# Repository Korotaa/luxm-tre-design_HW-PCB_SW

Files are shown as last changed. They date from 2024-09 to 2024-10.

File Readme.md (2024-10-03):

# TSL25711 sensor with LoRa module and ESP32 chip 

## Bloc Diagramm

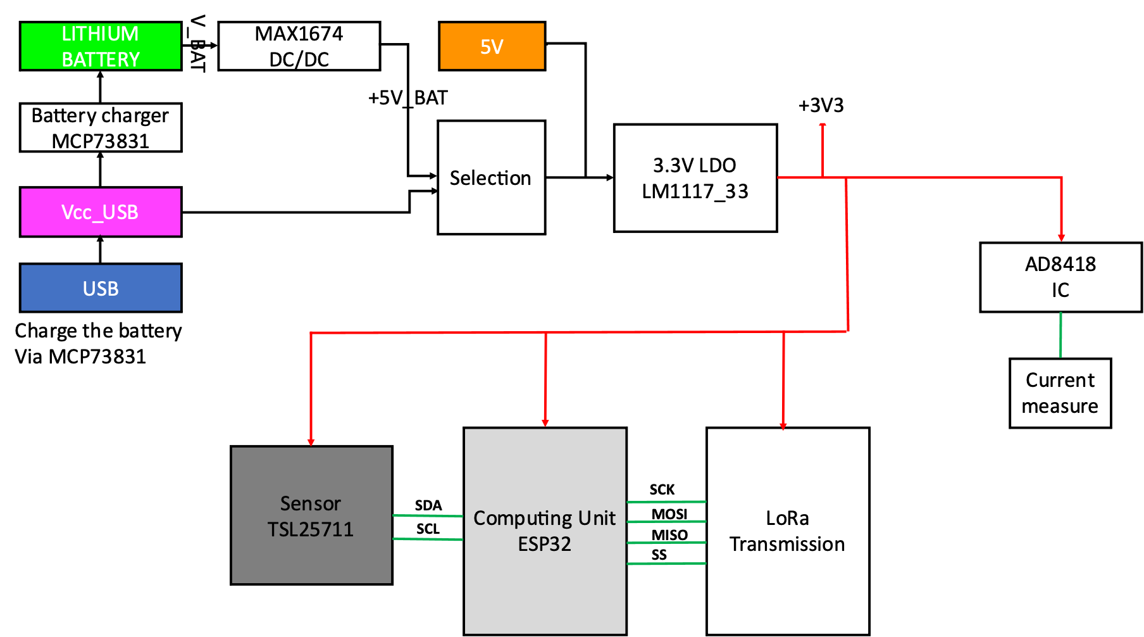
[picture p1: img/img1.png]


Le module est un End Device LoRa. C'est un dispositif IoT permettant de mesurer le niveau de luminosité grace au capteur TSL2571 et transmettre ces données à un serveur LoRaWAN (NetWork Serveur + Application Serveur) . Il peut recevoir des informations de commandes downlink de l'utilisateur.

- RF-LORA-868-SO : Transceiver LoRa pour la transmission et la reception de données sans fils. Il communique avec le MCU via une interface SPI. MISO_L pour l'envoie de données du transceiver vers le MCU et MOSI_L pour l'envoie des données du MCU vers le transceiver.
- TSL25711 : Dispositif sensible à la lumière ambiante. La valeur de sortie du capteur est transférée au MCU via l'interface I2C. Le MCU determine la valeur en LUX du rayonnement lumineux grace à une formule empirique. On retrouve le capteur dans les écrans de pc ou des smartphones. L'objectif est afin d’adapter l’intensité lumineuse émise par l’écran à la lumière ambiante, l’objectif étant de réduire la consommation de l’écran qui peut représenter jusqu’à 40% de l’énergie consommée.  
- MCU est un ESP32 
- Le dispositif possède 3 modes d'alimentations : USB, battery, ou par une alimentation externe. Lorsque le module est alimentée par USB, la batterie est chargée par la même occasion via le circuit MCP73831. 
- Il existe plusieurs points de tests permettant de visualiser grâce un oscilloscope les trames LoRa, la consommation de la carte etc...
- Le End Device est utilisé pour adapter l'éclairement d'un laboratoire en fonction de la lumière ambiante. 

- Le firmware est dévéloppé avec ESP-IDF. 

## PCB

<!-- ![](./img/routage.png) -->

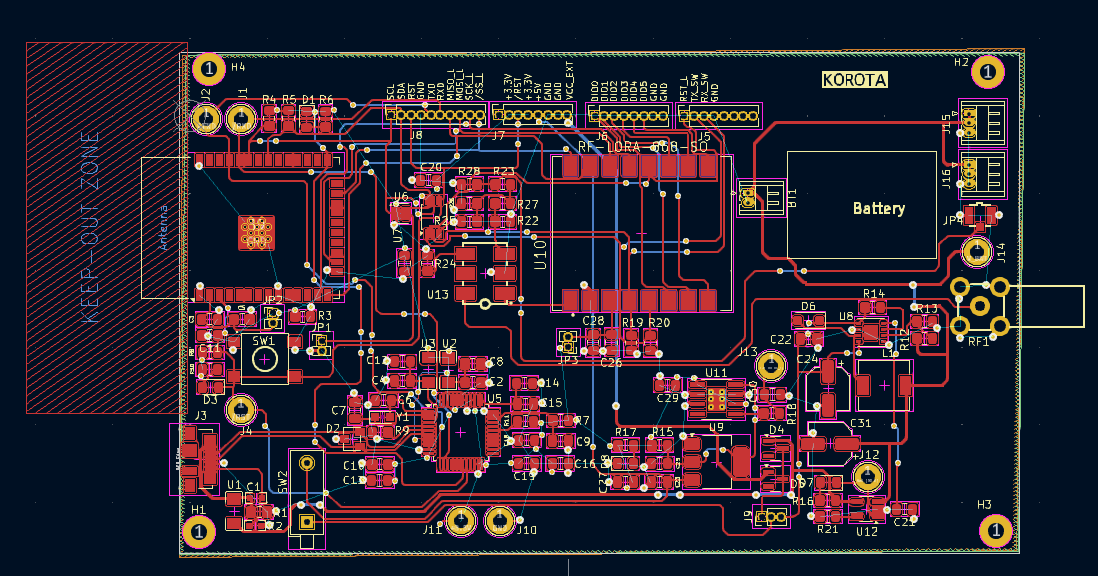
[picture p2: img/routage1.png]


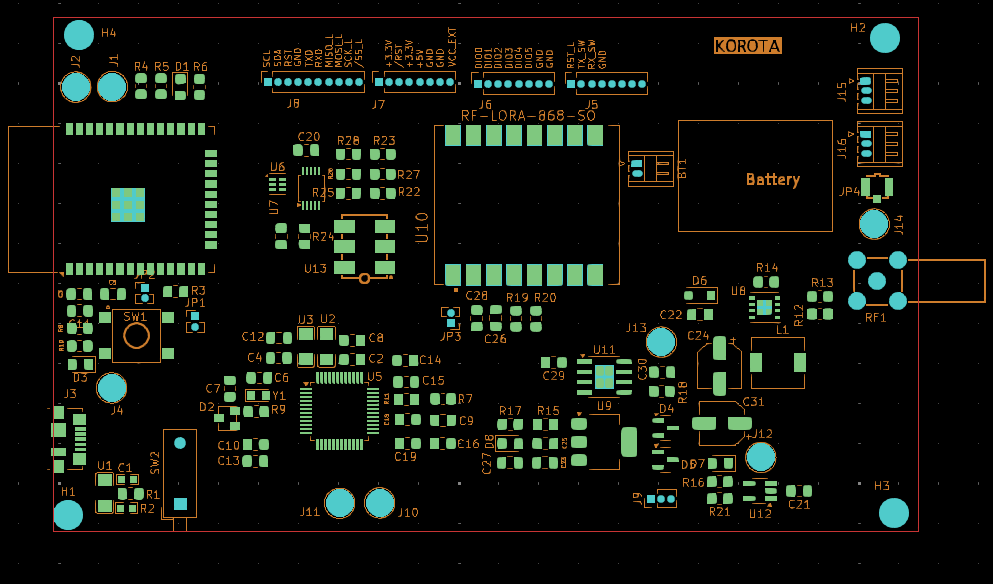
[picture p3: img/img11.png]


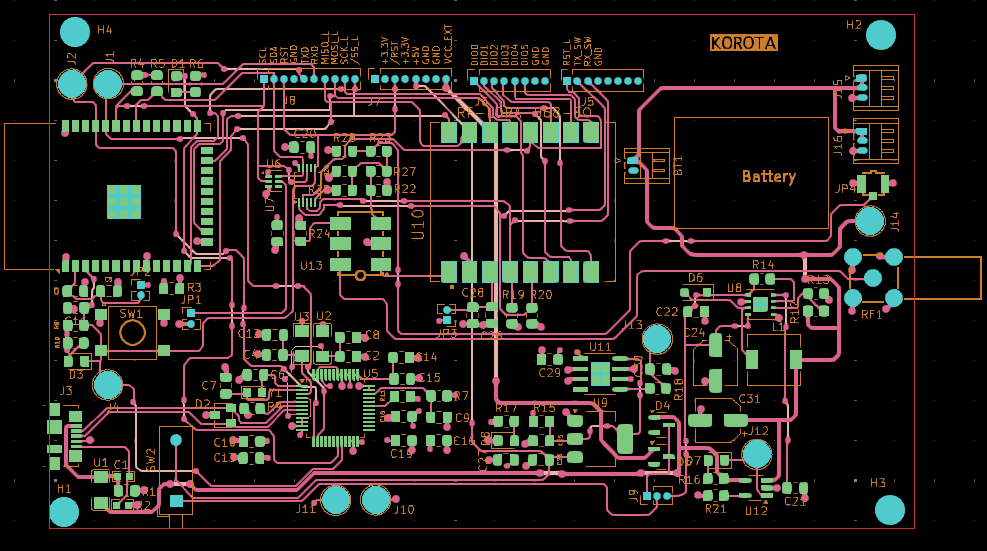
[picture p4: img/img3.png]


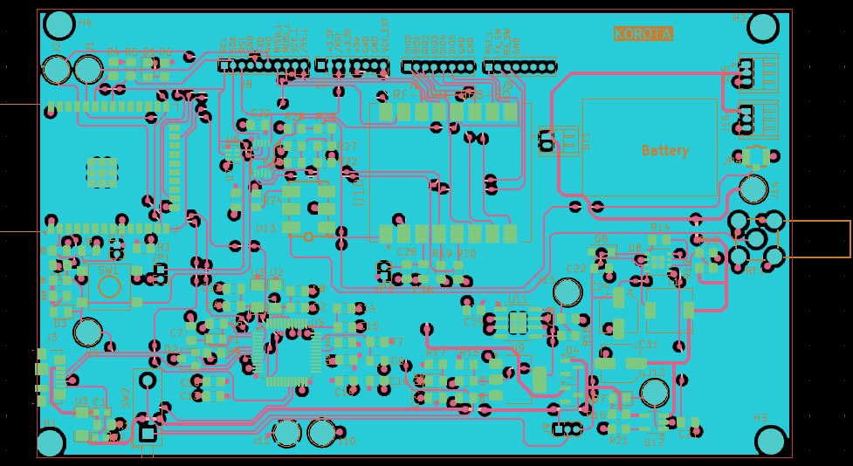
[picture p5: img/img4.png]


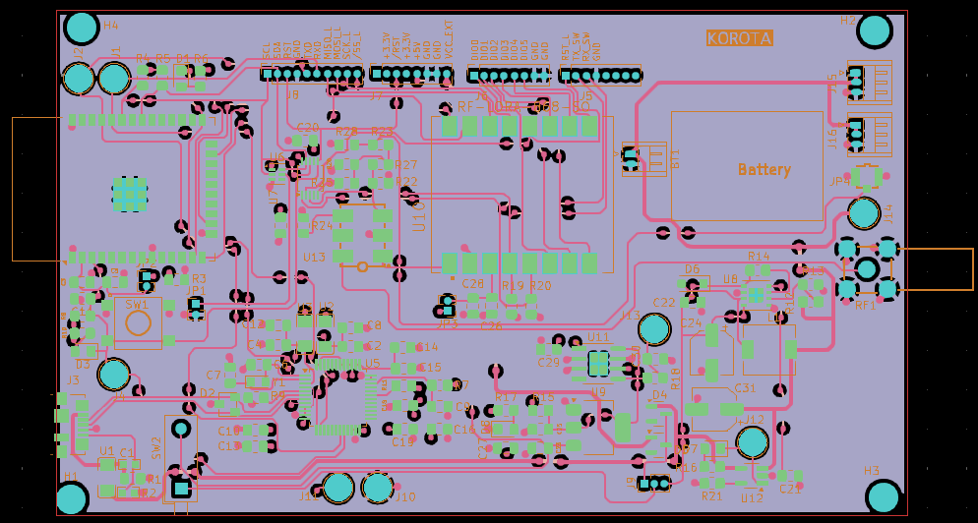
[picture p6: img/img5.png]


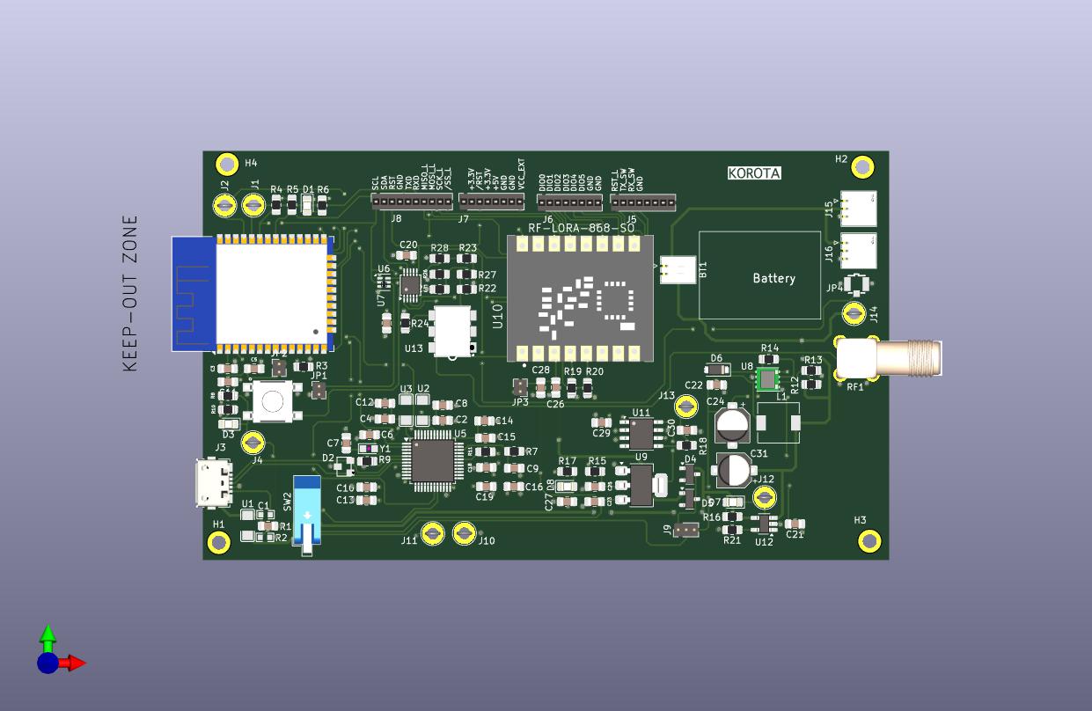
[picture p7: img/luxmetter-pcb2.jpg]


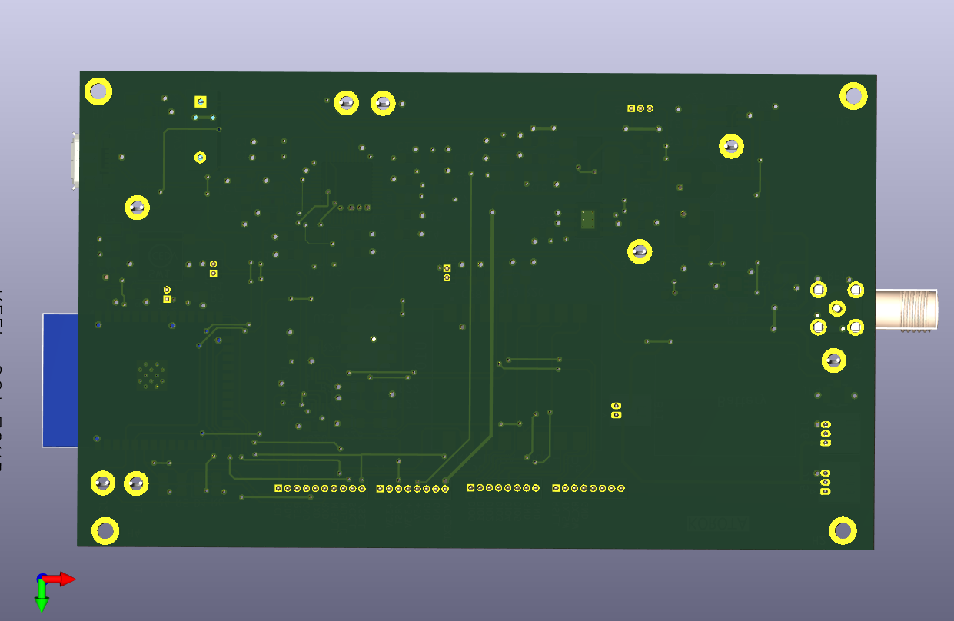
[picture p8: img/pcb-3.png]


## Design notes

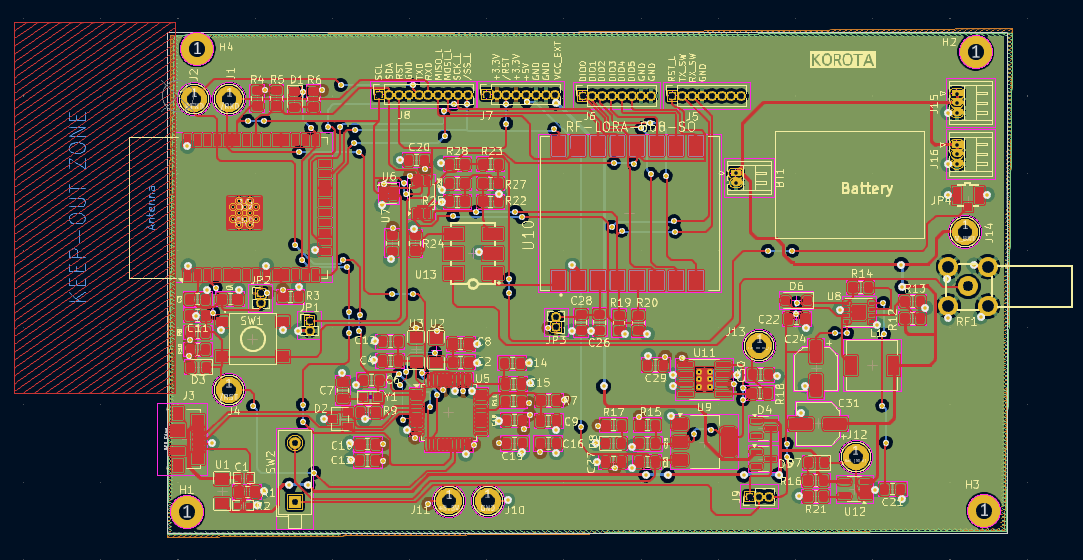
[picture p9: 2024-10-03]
img/routage.png

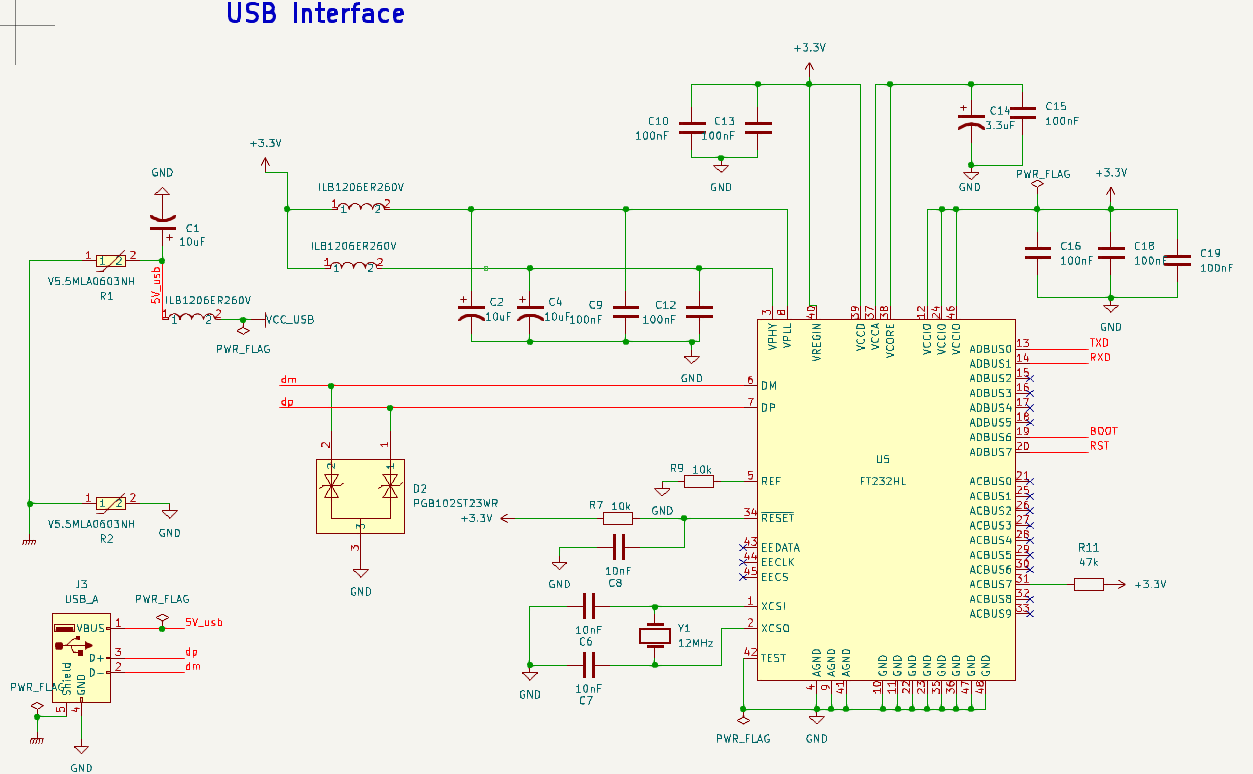
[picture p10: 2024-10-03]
img/usb.png

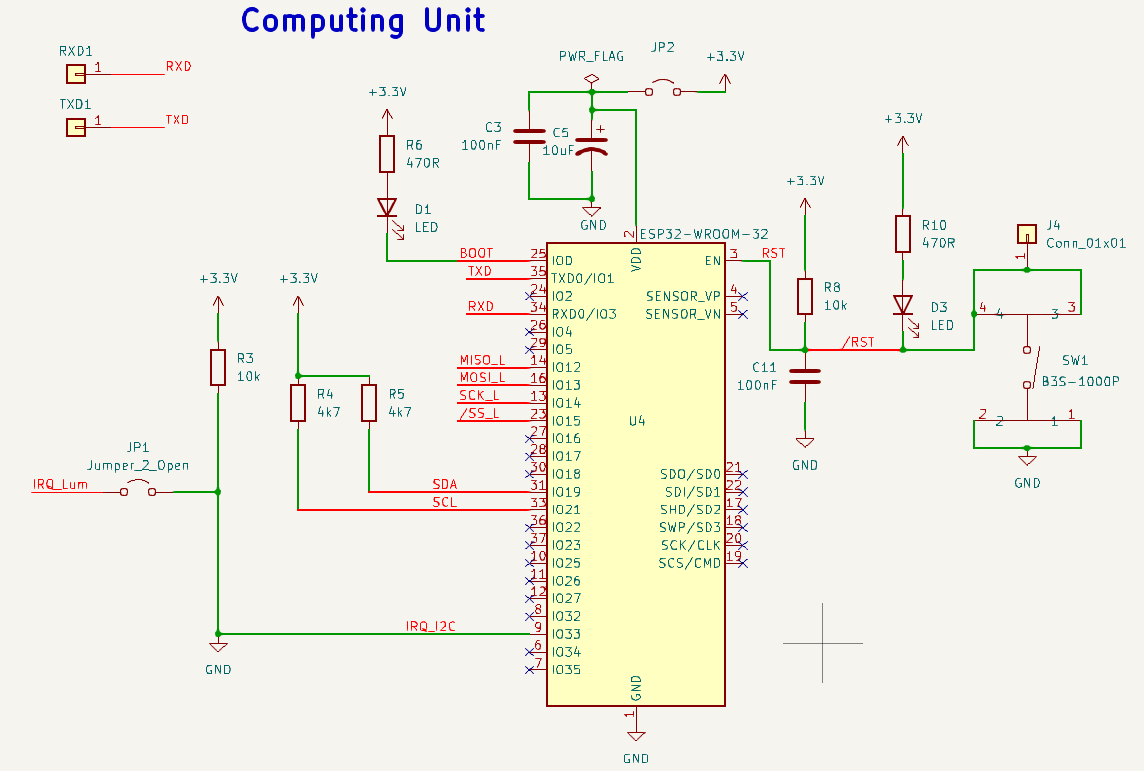
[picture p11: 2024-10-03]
img/computing-unit.png

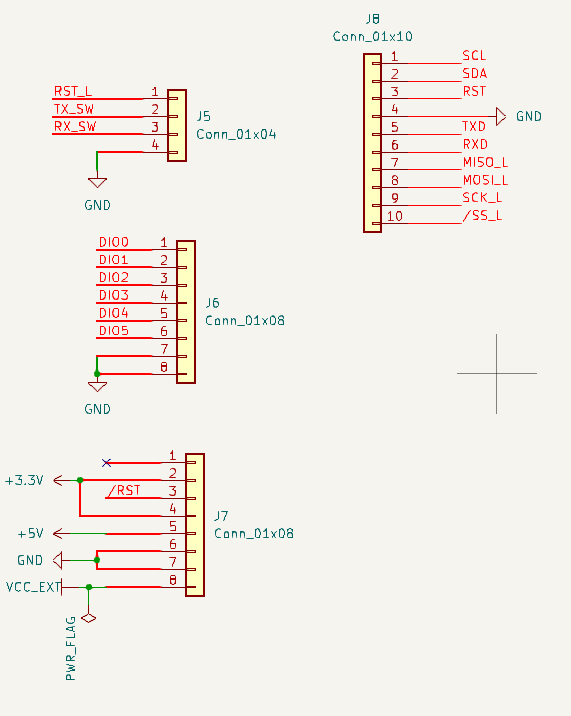
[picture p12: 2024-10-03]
img/connector.png

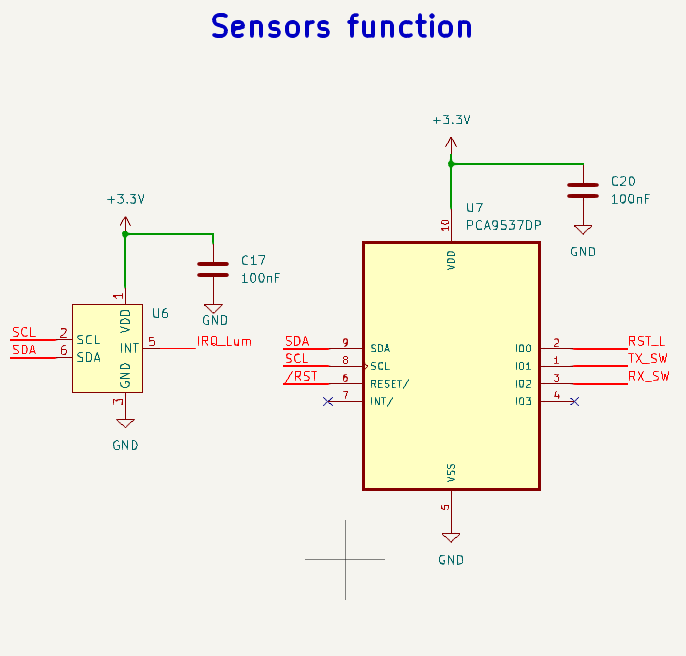
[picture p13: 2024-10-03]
img/sensors.png

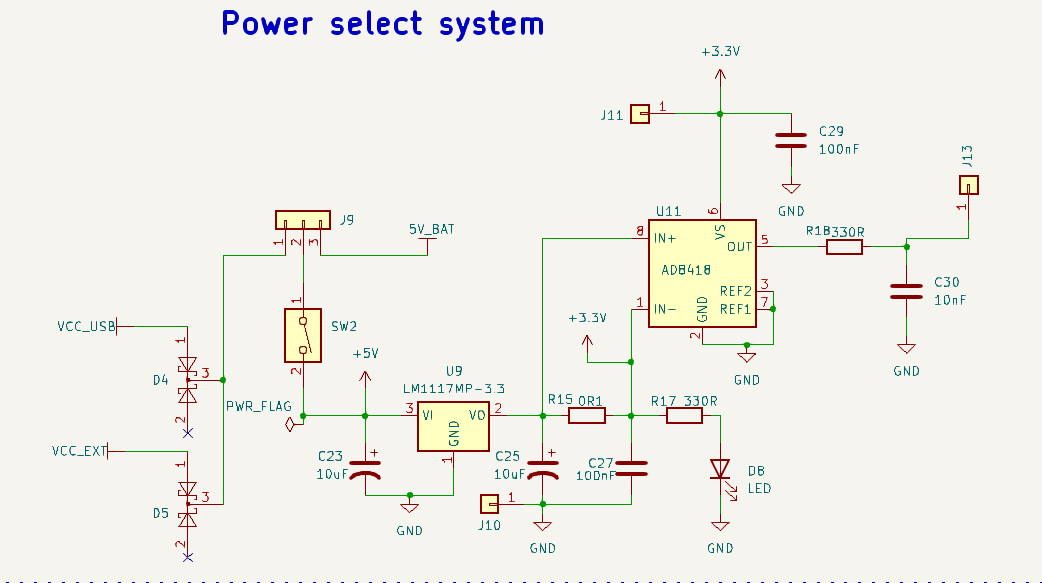
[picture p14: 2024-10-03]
img/power.png

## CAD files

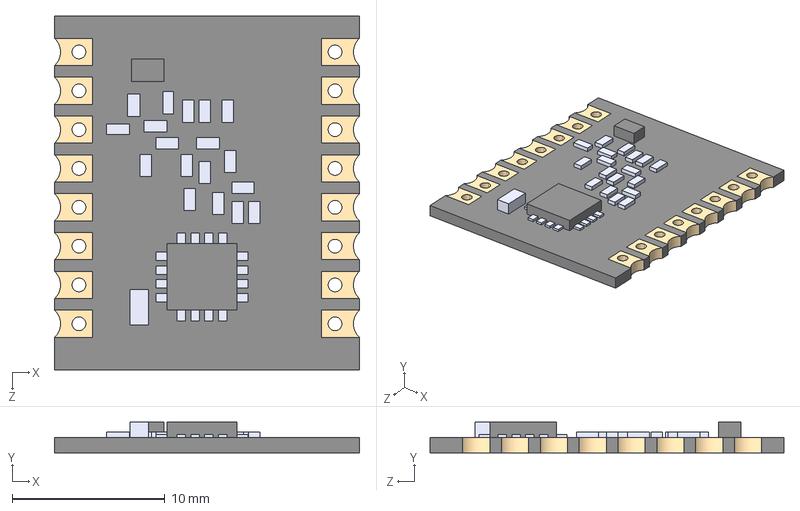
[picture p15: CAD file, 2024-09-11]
RF-LORA-868-SO/RF-LORA-868-SO.step
20.0 x 2.00 x 23.1 mm

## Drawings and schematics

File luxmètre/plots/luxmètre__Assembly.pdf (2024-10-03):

JP2 R4 | C4
1 | 2 | 3 | 4 | 5 | 6

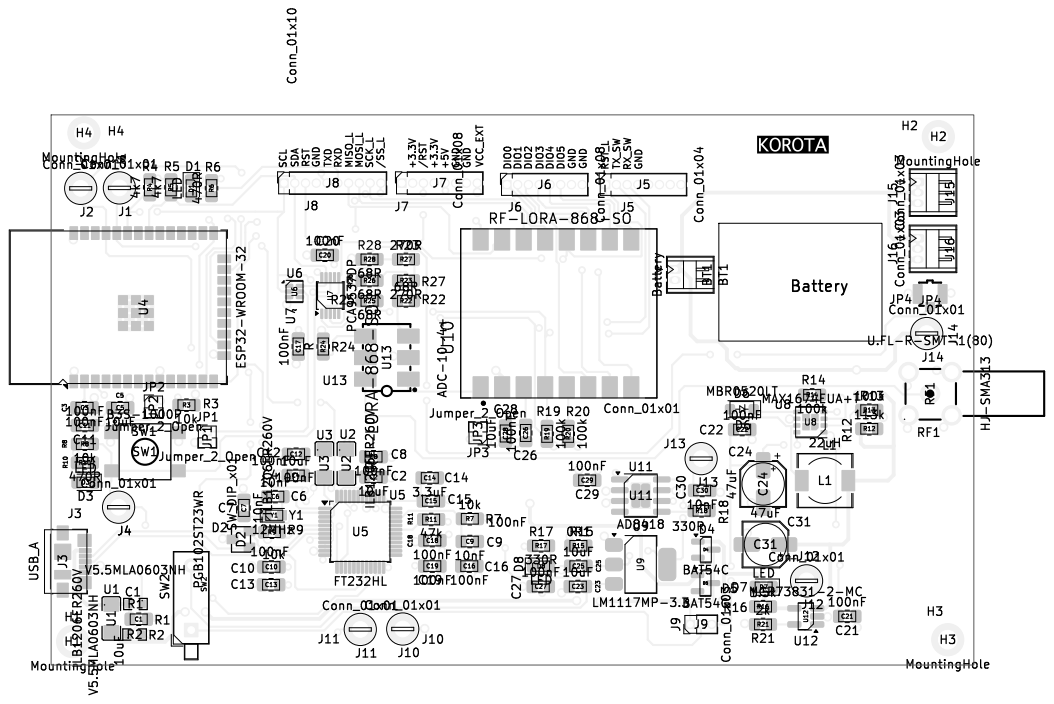
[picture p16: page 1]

U8 ESP³²⁻WROOM⁻³² U⁴

Id: 1/1 Title: File: luxmètre.kicad_pcb Sheet:

1 | 2 | 3 | 4 | 5 | 6

A

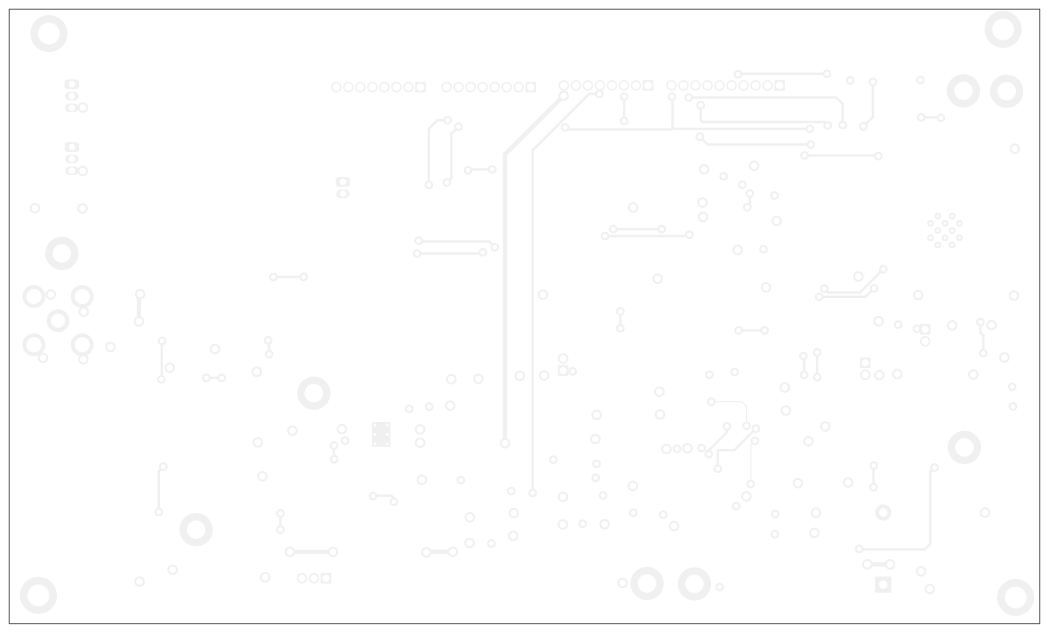
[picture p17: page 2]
D Date: KiCad; E.D.A. 8.0.3 Size: A4; Rev:

Id: 1/1 Title: File: luxmètre.kicad_pcb Sheet:

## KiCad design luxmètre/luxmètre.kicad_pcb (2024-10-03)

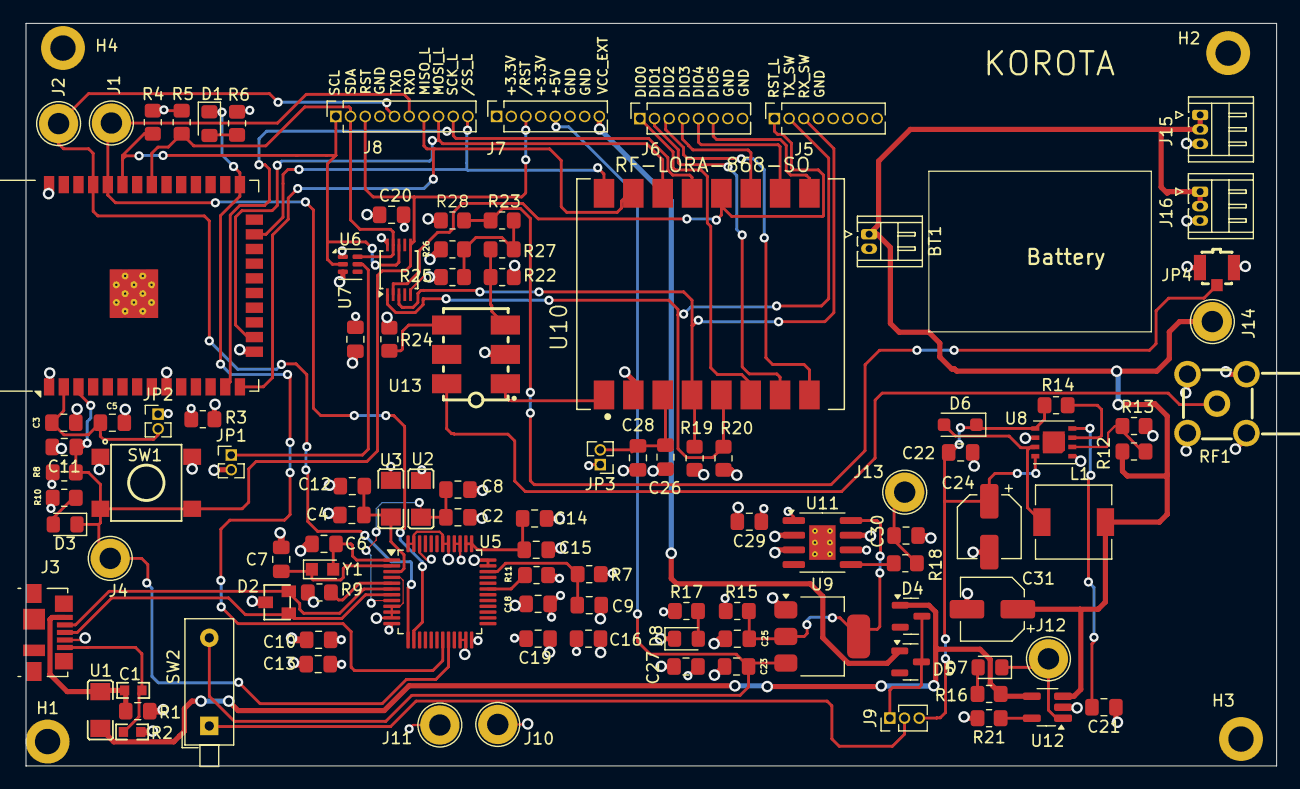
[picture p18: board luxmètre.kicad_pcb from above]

Board: 4 copper layers, 108.2 x 64.2 mm, 110 parts (0 on the bottom side), 62 nets.

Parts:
BT1: Battery; Hirose_DF13-02P-1.25DS_1x02_P1.25mm_Horizontal
C1, C2, C4, C5, C23, C25, C28: 10uF; C_0805_2012Metric_Pad1.18x1.45mm_HandSolder
C3, C8, C10, C11, C12, C13, C15, C16, C17, C18, C19, C20, C21, C22, C26, C27, C29: 100nF; C_0805_2012Metric_Pad1.18x1.45mm_HandSolder
C6, C7, C9, C30: 10nF; C_0805_2012Metric_Pad1.18x1.45mm_HandSolder
C14: 3.3uF; C_0805_2012Metric_Pad1.18x1.45mm_HandSolder
C24, C31: 47uF; CP_Elec_5x5.4
D1, D3, D7, D8: LED; LED_0805_2012Metric_Pad1.15x1.40mm_HandSolder
D2: PGB102ST23WR; SOT-23_L3.0-W2.2-P0.95-LS2.2-TR
D4, D5: BAT54C; SOT-23
D6: MBR0520LT; D_SOD-123F
H1, H2, H3, H4: MountingHole; MountingHole_2.2mm_M2_DIN965_Pad
J1, J2, J4, J10, J11, J12, J13, J14: Conn_01x01; TestPoint_Loop_D2.50mm_Drill1.85mm
J3: USB_A; USB_Micro-B_Molex_47346-0001
J5: Conn_01x04; PinSocket_1x08_P1.27mm_Vertical
J6, J7: Conn_01x08; PinSocket_1x08_P1.27mm_Vertical
J8: Conn_01x10; PinSocket_1x10_P1.27mm_Vertical
J9: Conn_01x03; PinHeader_1x03_P1.27mm_Vertical
J15, J16: Conn_01x03; Hirose_DF13-03P-1.25DS_1x03_P1.25mm_Horizontal
JP1, JP2, JP3: Jumper_2_Open; PinHeader_1x02_P1.27mm_Vertical
JP4: U.FL-R-SMT-1(80); RF-SMD_FRF05002-JSS103M
L1: 22uH; L_6.3x6.3_H3
R1, R2: V5.5MLA0603NH; R0603
R3, R7, R8, R9: 10k; R_0805_2012Metric_Pad1.20x1.40mm_HandSolder
R4, R5: 4k7; R_0805_2012Metric_Pad1.20x1.40mm_HandSolder
R6, R10: 470R; R_0805_2012Metric_Pad1.20x1.40mm_HandSolder
R11: 47k; R_0805_2012Metric_Pad1.20x1.40mm_HandSolder
R12: 113k; R_0805_2012Metric_Pad1.20x1.40mm_HandSolder
R13, R14, R19, R20: 100k; R_0805_2012Metric_Pad1.20x1.40mm_HandSolder
R15: 0R1; R_0805_2012Metric_Pad1.20x1.40mm_HandSolder
R16: 1.5k; R_0805_2012Metric_Pad1.20x1.40mm_HandSolder
R17, R18: 330R; R_0805_2012Metric_Pad1.20x1.40mm_HandSolder
R21: 2k; R_0805_2012Metric_Pad1.20x1.40mm_HandSolder
R22, R25, R26, R28: 68R; R_0805_2012Metric_Pad1.20x1.40mm_HandSolder
R23, R27: 270R; R_0805_2012Metric_Pad1.20x1.40mm_HandSolder
R24: R; R_0805_2012Metric_Pad1.20x1.40mm_HandSolder
RF1: HJ-SMA313; SMA-TH_HJ-2LC15SF048
SW1: B3S-1000P; KEY-SMD_4P-L6.6-W6.0-P4.50-LS9.0-BR
SW2: SW_DIP_x01; SW_DIP_SPSTx01_Piano_10.8x4.1mm_W7.62mm_P2.54mm
U1, U2, U3: ILB1206ER260V; L1206
U4: ESP32-WROOM-32
U5: FT232HL; LQFP-48_7x7mm_P0.5mm
U6: AMS_TSL25911FN
U7: PCA9537DP; TSSOP-10_3x3mm_P0.5mm
U8: MAX1674EUA+T; Converter_DCDC_Cyntec_MUN12AD01-SH
U9: LM1117MP-3.3; SOT-223-3_TabPin2
U10: RF-LORA-868-SO; XCVR_RF-LORA-868-SO
U11: AD8418; SOIC-8-1EP_3.9x4.9mm_P1.27mm_EP2.29x3mm_ThermalVias
U12: MCP73831-2-MC; SOT-23-5_HandSoldering
U13: ADC-10-4+; XFMR-SMD_6P-L7.9-W5.6-P2.54-LS7.0-BL
Y1: 12MHz; Crystal_SMD_2012-2Pin_2.0x1.2mm_HandSoldering

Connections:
5V_BAT: C22.2, C24.1, D6.1 (K), J9.3, R14.1, U8.5 (~SHDN), U8.8 (OUT)
+3.3V: C10.1, C13.2, C16.1, C17.1, C18.2, C19.1, C20.1, C27.1, C29.1, J7.2, J7.4, J11.1, JP2.1 (A), JP3.1 (A), R3.1, R4.1, R5.1, R6.1, R7.1, R8.1, R10.1, R11.2, R15.2, R17.1, U2.1, U3.1, U5.12 (VCCIO), U5.24 (VCCIO), U5.39 (VCCD), U5.40 (VREGIN), U5.46 (VCCIO), U6.1 (VDD), U7.10 (VDD), U11.1 (IN-), U11.6 (VS)
+5V: C23.1, J7.5, SW2.2, U9.3 (VI)
/5V_usb: C1.1, J3.1 (VBUS), R1.2, U1.1
/ANT: U10.1 (ANT), U13.1 (INPUT)
/BOOT: D1.1 (K), U4.25 (IO0), U5.19 (ADBUS6)
/C: R22.2, R23.1, U13.3 (COUPLED)
/DIO0: J6.1, U10.6 (DIO0)
/DIO1: J6.2, U10.7 (DIO1)
/DIO2: J6.3, U10.8 (DIO2)
/DIO3: J6.4, U10.11 (DIO5)
/DIO4: J6.5, U10.10 (DIO4)
/DIO5: J6.6, U10.9 (DIO3)
/IRQ_Lum: JP1.1 (A), U6.5 (INT)
/MISO_L: J8.7, U4.14 (IO12), U10.15 (SDI)
/MOSI_L: J8.8, U4.16 (IO13), U10.14 (SDO)
/RST: C11.1, D3.1 (K), J4.1, J7.3, J8.3, R8.2, SW1.3, SW1.4, U4.3 (EN), U5.20 (ADBUS7), U7.6 (RESET/)
/RST_L: J5.1, U7.2 (IO0), U10.12 (RESET)
/RXD: J1.1, J8.6, U4.34 (RXD0/IO3), U5.14 (ADBUS1)
/RX_SW: J5.3, R19.2, U7.3 (IO2), U10.4 (RX_SWITCH)
/SCK_L: J8.9, U4.13 (IO14), U10.13 (SCLK)
/SCL: J8.1, R4.2, U4.33 (IO21), U6.2 (SCL), U7.8 (SCL)
/SDA: J8.2, R5.2, U4.31 (IO19), U6.6 (SDA), U7.9 (SDA)
/TXD: J2.1, J8.5, U4.35 (TXD0/IO1), U5.13 (ADBUS0)
/TX_SW: J5.2, R20.2, U7.1 (IO1), U10.5 (TX_SWITCH)
/dm: D2.2, J3.2 (D-), U5.6 (DM)
/dp: D2.1, J3.3 (D+), U5.7 (DP)
//SS_L: J8.10, U4.23 (IO15), U10.16 (~SEL)
GND: BT1.2 (-), C1.2, C2.2, C3.2, C4.2, C5.2, C6.2, C7.2, C8.2, C9.2, C10.2, C11.2, C12.1, C13.1, C14.2, C15.2, C16.2, C17.2, C18.1, C19.2, C20.2, C21.1, C22.1, C23.2, C24.2, C25.2, C26.2, C27.2, C28.2, C29.2, C30.2, C31.2, D2.3, D8.1 (K), J3.4 (GND), J5.4, J6.7, J6.8, J7.6, J7.7, J8.4, J10.1, J15.3, J16.3, JP1.2 (B), JP4.2 (GND), JP4.3 (GND), R2.2, R3.2, R9.1, R13.1, R19.1, R20.1, R21.2, R22.1, R24.1, R25.1, R26.1, R28.1, RF1.2, RF1.3, RF1.4, RF1.5, SW1.1, SW1.2, U4.1 (GND), U4.9 (IO33), U4.15 (GND), U4.38 (GND), U4.39 (GND), U5.4 (AGND), U5.9 (AGND), U5.10 (GND), U5.11 (GND), U5.22 (GND), U5.23 (GND), U5.35 (GND), U5.36 (GND), U5.41 (AGND), U5.42 (TEST), U5.47 (GND), U5.48 (GND), U6.3 (GND), U7.5 (VSS), U8.1 (FB), U8.6 (GND), U9.1 (GND), U10.2 (GND), U11.2 (GND), U11.3 (REF2), U11.7 (REF1), U12.2 (V_{SS}), U13.2 (GROUND)
GNDPWR: J3.5 (Shield), R1.1, R2.1
unnamed: D1.2 (A), R6.2
unnamed: D3.2 (A), R10.2
unnamed: D6.2 (A), L1.2, U8.7 (LX)
unnamed: D7.2 (A), R16.2
unnamed: D7.1 (K), J12.1, U12.1 (STAT)
unnamed: D8.2 (A), R17.2
unnamed: D4.3, D5.3, J9.1
unnamed: J9.2, SW2.1
unnamed: C30.1, J13.1, R18.2
unnamed: C3.1, C5.1, JP2.2 (B), U4.2 (VDD)
unnamed: C26.1, C28.1, JP3.2 (B), U10.3 (VCC)
unnamed: JP4.1 (SIG), R27.2, R28.2
unnamed: R23.2, R25.2, R26.2, R27.1
unnamed: R11.1, U5.31 (ACBUS7)
unnamed: R9.2, U5.5 (REF)
unnamed: C14.1, C15.1, U5.37 (VCCA), U5.38 (VCORE)
unnamed: C4.1, C12.2, U3.2, U5.3 (VPHY)
unnamed: C2.1, C8.1, U2.2, U5.8 (VPLL)
unnamed: C6.1, U5.1 (XCSI), Y1.2
unnamed: C7.1, U5.2 (XCSO), Y1.1
unnamed: C9.1, R7.2, U5.34 (~RESET)
unnamed: R12.1, R13.2, U8.2 (LBI)
unnamed: C21.2, U8.4 (REF)
unnamed: R14.2, U8.3 (~LBO)
unnamed: C25.1, R15.1, U9.2 (VO), U11.8 (IN+)
unnamed: R18.1, U11.5 (OUT)
unnamed: R21.1, U12.5 (PROG)
unnamed: RF1.1, U13.6 (OUTPUT)
unnamed: R24.2, U13.4 (TERM)
VCC_EXT: D5.1, J7.8
VCC_USB: D4.1, R16.1, U1.2, U12.4 (V_{DD})
V_BAT: BT1.1 (+), C31.1, J14.1, J15.1, J15.2, J16.1, J16.2, L1.1, R12.2, U12.3 (V_{BAT})

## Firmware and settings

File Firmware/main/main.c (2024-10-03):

#include "freertos/FreeRTOS.h"
#include "freertos/task.h"
#include "esp_wifi.h"
#include "esp_system.h"
#include "esp_event.h"
#include "esp_event_loop.h"
#include "esp_log.h"
#include "nvs_flash.h"

#include "soc/gpio_struct.h"
#include "driver/gpio.h"

#include "lmic.h"
#include "eid430.h"

#include "Gestion_TOR.h"
#include "Gestion_Lum.h"

#include "lorawan_cnf.h"
#include "lorawan.h"

//Timing d'emmission (en ms / Typique 2000 / valeur min 500)
uint16_t Interval_Env=2000;

//Variables texte
static uint8_t mydata[] = "korota";

void SendDataLUM()
{

    printf("\r\n\r\n     ========= ENVOIE DES DATA SUR LORAWAN  =========     \r\n\r\n");
    gpio_set_level(LED0_IO,1);
    
    if (send_lum==true)
        {
        printf("Send Data LUM...\r\n");
        LMIC_setTxData2(LORAWAN_PORT_Lum,&lum_current,sizeof(lum_current),0);
        send_lum=false;
        }else
          {
          printf("Envoie texte...\r\n");
          LMIC_setTxData2(LORAWAN_PORT_ChaineCarac,mydata, sizeof(mydata)-1,0);
          }

    gpio_set_level(LED1_IO,0);
    printf("     ===============================================     \r\n\r\n");
    vTaskDelay(2000 / portTICK_RATE_MS);

}


void app_main(void)
{
    //Config led 
    printf("Init LED0...\r\n");  
    gpio_pad_select_gpio(LED0_IO);
    gpio_set_direction(LED0_IO,GPIO_MODE_DEF_OUTPUT);
    gpio_set_level(LED0_IO,0);
    
    // Fonction qui initialise la couche Lora et crée la tache principale de l'ordonanceur os_runloop
    InitLoRaWAN(SendDataLUM);
    //InitI2c();  // A ajouter ssi InitLoRaWAN(..) n'est pas actif
    vTaskDelay(500/ portTICK_PERIOD_MS); //attente
    
    // Fonction qui initialise crée la tache qui va récupérer la valeur du Lumetre
    InitGestionLum();
}

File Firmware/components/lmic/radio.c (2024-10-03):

/*
 * Copyright (c) 2014-2016 IBM Corporation.
 * All rights reserved.
 *
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
 * THIS SOFTWARE IS PROVIDED BY THE COPYRIGHT HOLDERS AND CONTRIBUTORS "AS IS" AND
 * ANY EXPRESS OR IMPLIED WARRANTIES, INCLUDING, BUT NOT LIMITED TO, THE IMPLIED
 * WARRANTIES OF MERCHANTABILITY AND FITNESS FOR A PARTICULAR PURPOSE ARE
 * DISCLAIMED. IN NO EVENT SHALL <COPYRIGHT HOLDER> BE LIABLE FOR ANY
 * DIRECT, INDIRECT, INCIDENTAL, SPECIAL, EXEMPLARY, OR CONSEQUENTIAL DAMAGES
 * (INCLUDING, BUT NOT LIMITED TO, PROCUREMENT OF SUBSTITUTE GOODS OR SERVICES;
 * LOSS OF USE, DATA, OR PROFITS; OR BUSINESS INTERRUPTION) HOWEVER CAUSED AND
 * ON ANY THEORY OF LIABILITY, WHETHER IN CONTRACT, STRICT LIABILITY, OR TORT
 * (INCLUDING NEGLIGENCE OR OTHERWISE) ARISING IN ANY WAY OUT OF THE USE OF THIS
 * SOFTWARE, EVEN IF ADVISED OF THE POSSIBILITY OF SUCH DAMAGE.
 */
#include <stdio.h>
#include "esp_system.h"
#include "lmic.h"
#include "eid430.h"

// ----------------------------------------
// Registers Mapping
#define RegFifo                                    0x00 // common
#define RegOpMode                                  0x01 // common
#define FSKRegBitrateMsb                           0x02
#define FSKRegBitrateLsb                           0x03
#define FSKRegFdevMsb                              0x04
#define FSKRegFdevLsb                              0x05
#define RegFrfMsb                                  0x06 // common
#define RegFrfMid                                  0x07 // common
#define RegFrfLsb                                  0x08 // common
#define RegPaConfig                                0x09 // common
#define RegPaRamp                                  0x0A // common
#define RegOcp                                     0x0B // common
#define RegLna                                     0x0C // common
#define FSKRegRxConfig                             0x0D
#define LORARegFifoAddrPtr                         0x0D
#define FSKRegRssiConfig                           0x0E
#define LORARegFifoTxBaseAddr                      0x0E
#define FSKRegRssiCollision                        0x0F
#define LORARegFifoRxBaseAddr                      0x0F
#define FSKRegRssiThresh                           0x10
#define LORARegFifoRxCurrentAddr                   0x10
#define FSKRegRssiValue                            0x11
#define LORARegIrqFlagsMask                        0x11
#define FSKRegRxBw                                 0x12
#define LORARegIrqFlags                            0x12
#define FSKRegAfcBw                                0x13
#define LORARegRxNbBytes                           0x13
#define FSKRegOokPeak                              0x14
#define LORARegRxHeaderCntValueMsb                 0x14
#define FSKRegOokFix                               0x15
#define LORARegRxHeaderCntValueLsb                 0x15
#define FSKRegOokAvg                               0x16
#define LORARegRxPacketCntValueMsb                 0x16
#define LORARegRxpacketCntValueLsb                 0x17
#define LORARegModemStat                           0x18
#define LORARegPktSnrValue                         0x19
#define FSKRegAfcFei                               0x1A
#define LORARegPktRssiValue                        0x1A
#define FSKRegAfcMsb                               0x1B
#define LORARegRssiValue                           0x1B
#define FSKRegAfcLsb                               0x1C
#define LORARegHopChannel                          0x1C
#define FSKRegFeiMsb                               0x1D
#define LORARegModemConfig1                        0x1D
#define FSKRegFeiLsb                               0x1E
#define LORARegModemConfig2                        0x1E
#define FSKRegPreambleDetect                       0x1F
#define LORARegSymbTimeoutLsb                      0x1F
#define FSKRegRxTimeout1                           0x20
#define LORARegPreambleMsb                         0x20
#define FSKRegRxTimeout2                           0x21
#define LORARegPreambleLsb                         0x21
#define FSKRegRxTimeout3                           0x22
#define LORARegPayloadLength                       0x22
#define FSKRegRxDelay                              0x23
#define LORARegPayloadMaxLength                    0x23
#define FSKRegOsc                                  0x24
#define LORARegHopPeriod                           0x24
#define FSKRegPreambleMsb                          0x25
#define LORARegFifoRxByteAddr                      0x25
#define LORARegModemConfig3                        0x26
#define FSKRegPreambleLsb                          0x26
#define FSKRegSyncConfig                           0x27
#define LORARegFeiMsb                              0x28
#define FSKRegSyncValue1                           0x28
#define LORAFeiMib                                 0x29
#define FSKRegSyncValue2                           0x29
#define LORARegFeiLsb                              0x2A
#define FSKRegSyncValue3                           0x2A
#define FSKRegSyncValue4                           0x2B
#define LORARegRssiWideband                        0x2C
#define FSKRegSyncValue5                           0x2C
#define FSKRegSyncValue6                           0x2D
#define FSKRegSyncValue7                           0x2E
#define FSKRegSyncValue8                           0x2F
#define FSKRegPacketConfig1                        0x30
#define FSKRegPacketConfig2                        0x31
#define LORARegDetectOptimize                      0x31
#define FSKRegPayloadLength                        0x32
#define FSKRegNodeAdrs                             0x33
#define LORARegInvertIQ                            0x33
#define FSKRegBroadcastAdrs                        0x34
#define FSKRegFifoThresh                           0x35
#define FSKRegSeqConfig1                           0x36
#define FSKRegSeqConfig2                           0x37
#define LORARegDetectionThreshold                  0x37
#define FSKRegTimerResol                           0x38
#define FSKRegTimer1Coef                           0x39
#define LORARegSyncWord                            0x39
#define FSKRegTimer2Coef                           0x3A
#define FSKRegImageCal                             0x3B
#define FSKRegTemp                                 0x3C
#define FSKRegLowBat                               0x3D
#define FSKRegIrqFlags1                            0x3E
#define FSKRegIrqFlags2                            0x3F
#define RegDioMapping1                             0x40 // common
#define RegDioMapping2                             0x41 // common
#define RegVersion                                 0x42 // common
// #define RegAgcRef                                  0x43 // common
// #define RegAgcThresh1                              0x44 // common
// #define RegAgcThresh2                              0x45 // common
// #define RegAgcThresh3                              0x46 // common
// #define RegPllHop                                  0x4B // common
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
